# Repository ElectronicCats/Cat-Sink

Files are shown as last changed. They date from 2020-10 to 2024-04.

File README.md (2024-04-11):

# CatSink - USB power supply with PD

<p align="center">
    <a href="https://github.com/ElectronicCats/Cat-Sink/wiki">
        
    </a>
</p>

<p align=center>
    <a href="https://electroniccats.com/store/catsink-usb-c-pd/">
        
    </a>
    <a href="https://github.com/ElectronicCats/Cat-Sink/wiki">
        
    </a>
</p>

A USB-C PD Sink up to 20V 5A based on the Cypress CYPD3177 USB PD Controller

USB-C PD offers the option to negotiate power delivery from a compatible power supply. This board plays the role of a sink device, enabling any device to be powered by a USB power supply. Any type of power connector can be attached through a 2-pin screw terminal or directly soldered into the PCB for a lower profile. The voltage can be set to 5V, 9V, 12V, or 20V and the maximum negotiable current can be set to 1A, 2A, 3A, or 5A. Other voltage or current settings are possible by changing resistors. No programming is needed.

## How to contribute 
 Contributions are welcome! 

Please read the document  [**Contribution Manual**](https://github.com/ElectronicCats/electroniccats-cla/blob/main/electroniccats-contribution-manual.md)  which will show you how to contribute your changes to the project.

✨ Thanks to all our [contributors](https://github.com/ElectronicCats/Cat-Sink/graphs/contributors)! ✨

See [**_Electronic Cats CLA_**](https://github.com/ElectronicCats/electroniccats-cla/blob/main/electroniccats-cla.md) for more information.

See the  [**community code of conduct**](https://github.com/ElectronicCats/electroniccats-cla/blob/main/electroniccats-community-code-of-conduct.md) for a vision of the community we want to build and what we expect from it."						

## License

<a href="https://github.com/ElectronicCats">



</a>

<br />This work is licensed under the <a rel="license" href="http://creativecommons.org/licenses/by-sa/4.0/">Creative Commons Attribution-ShareAlike 4.0 International License</a>.

Electronic Cats invests time and resources in providing this open-source design, please support Electronic Cats and open-source hardware by purchasing products from Electronic Cats!

Designed by Electronic Cats.

Firmware released under an GNU AGPL v3.0 license. See the LICENSE file for more information.

Hardware released under an CERN Open Hardware Licence v1.2. See the LICENSE_HARDWARE file for more information.

Electronic Cats is a registered trademark, please do not use it if you sell these PCBs.

Octuber 2020

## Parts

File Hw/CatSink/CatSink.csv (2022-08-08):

Item | Qty | Reference(s) | Value | lcsc | manf#
1 | 2 | C1, C10 | 3.3uF | C76663
2 | 2 | C2, C3 | 390pF | C376830
3 | 4 | C4, C5, C6, C7 | 1uF | C26413
4 | 2 | C8, C9 | 0.1uF | C149620
5 | 1 | D1 | NZH10C | C551630 | NZH10C,115
6 | 1 | D2 | Fault | C84268
7 | 1 | D3 | Power | C118330
8 | 1 | J1 | Vout
9 | 1 | P1 | USB_C_Plug_USB2.0 | C393939
10 | 2 | Q1, Q2 | SI3421DV | C144884 | SI3421DV-T1-GE3
11 | 2 | R1, R5 | 2.4K | C98728
12 | 4 | R2, R6, R13, R18 | 1K | C115325
13 | 1 | R3 | 0R |  | ERJ-3GEY0R00V
14 | 5 | R4, R7, R8, R9, R10 | 5.1K | C131715
15 | 5 | R11, R14, R15, R16, R17 | 10K | C99198
16 | 1 | R12 | 50K | C304067
17 | 1 | SW1 | Voltage | C145846 | K3-1410S-E1
18 | 1 | SW2 | Current | C145846 | K3-1410S-E1
19 | 1 | U1 | CYPD3177-24LQXI |  | CYPD3177-24LQXQ

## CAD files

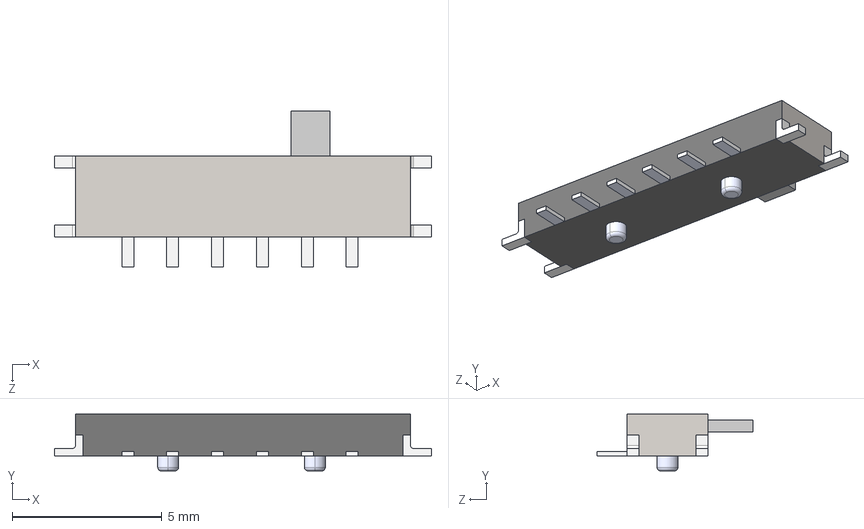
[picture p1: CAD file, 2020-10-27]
Hw/CatSink/3D/Pieza1.STEP
12.6 x 1.90 x 5.20 mm

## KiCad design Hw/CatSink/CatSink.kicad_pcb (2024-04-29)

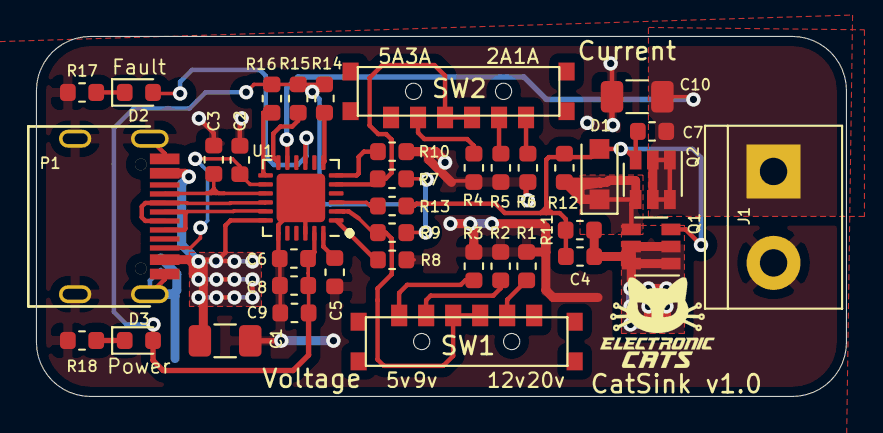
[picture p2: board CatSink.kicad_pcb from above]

Board: 2 copper layers, 45.0 x 20.0 mm, 38 parts (0 on the bottom side), 28 nets.

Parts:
C1, C10: 3.3uF; C_1206_3216Metric
C2, C3: 390pF; C_0603_1608Metric
C4, C5, C6, C7: 1uF; C_0603_1608Metric
C8, C9: 0.1uF; C_0603_1608Metric
D1: NZH10C; D_SOD-123F
D2: Fault; LED_0603_1608Metric
D3: Power; LED_0603_1608Metric
J1: Vout; TerminalBlock_bornier-2_P5.08mm
P1: USB_C_Plug_USB2.0; C393939
Q1, Q2: SI3421DV; SOT-23-6
R1, R5: 2.4K; R_0603_1608Metric
R2, R6, R13, R18: 1K; R_0603_1608Metric
R3: 0R; R_0603_1608Metric
R4, R7, R8, R9, R10: 5.1K; R_0603_1608Metric
R11, R14, R15, R16, R17: 10K; R_0603_1608Metric
R12: 50K; R_0603_1608Metric
SW1: Voltage; K3-1410S-E1
SW2: Current; K3-1410S-E1
U1: CYPD3177-24LQXI; QFN-24-1EP_4x4mm_P0.5mm_EP2.7x2.7mm

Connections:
+3V3: C6.1, C8.1, C9.1, D3.2, R7.1, R9.1, R14.1, R15.1, R16.1, U1.23
+VSW: C7.1, C10.1, J1.1, Q2.1, Q2.2, Q2.5, Q2.6, U1.11
/1A: R6.1, SW2.1
/2A: R5.1, SW2.2
/3A: R4.1, SW2.5
/5v: R3.1, SW1.1
/9v: R2.1, SW1.2
/12v: R1.1, SW1.5
/CC1: C3.1, P1.A5, U1.15
/CC2: C2.1, P1.B5, U1.14
/D+: P1.A6, U1.17
/D-: P1.A7, U1.16
/Fault: D2.2, U1.9
/Icoarse: R7.2, SW2.3, SW2.4, U1.5
/Vmax: R9.2, SW1.3, SW1.4, U1.2
GND: C1.2, C2.2, C3.2, C5.2, C6.2, C8.2, C9.2, C10.2, J1.2, P1.A1, P1.S1, R1.2, R2.2, R3.2, R4.2, R5.2, R6.2, R8.2, R10.2, R17.2, R18.2, U1.19, U1.22, U1.25
unnamed: C4.2, C7.2, D1.2, Q1.3, Q2.3, R11.2, R12.2, R13.1
unnamed: C5.1, U1.24
unnamed: D1.1, Q1.4, Q2.4, R12.1
unnamed: D2.1, R17.1
unnamed: D3.1, R18.1
unnamed: R8.1, U1.1
unnamed: R10.1, U1.6
unnamed: R13.2, U1.3
unnamed: R14.2, U1.7
unnamed: R15.2, U1.12
unnamed: R16.2, U1.13
VBUS: C1.1, C4.1, P1.A4, Q1.1, Q1.2, Q1.5, Q1.6, R11.1, U1.18

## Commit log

2020-10-24 add project v1.0
    [CatSink.kicad_pcb, CatSink.sch]
2020-10-24 fix traces add gitignore
    [CatSink.kicad_pcb, CatSink.sch]
2020-10-25 fix pcb
    [CatSink.kicad_pcb]
2020-10-26 added logos
    [CatSink.kicad_pcb]
2020-10-27 Added Led and 3D switch
    [CatSink.kicad_pcb, CatSink.sch, Pieza1.STEP]
2020-10-27 fix traces
    [CatSink.kicad_pcb]
2020-11-27 update BOM
    [CatSink.sch]
2021-01-20 update kicad project
    [CatSink.csv, CatSink.sch]
2024-04-29 fix (hw): change notations from margin to user drawings
    [CatSink.kicad_pcb]
